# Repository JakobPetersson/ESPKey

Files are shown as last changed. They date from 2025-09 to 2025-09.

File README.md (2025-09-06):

### What the heck is this anyway?
ESPKey is a small device which can be implanted into facility access control systems.  ESPKey is compatible with pretty much every door that requires a card swipe or tap with optional pin code to unlock.  It even works on many systems requiring finger print or other biometric authentication.  Inserting an ESPKey behind a card reader is better than a skimmer because not only can it log all authorized use of a system, it can also inject or replay captured credentials.  Once ESPKey shows you what credentials work on this door, use your favorite RFID tools to clone or simulate those credentials for use on other doors.  Want to show someone how insecure their facility is?  This is an incredibly easy way to start.

In case you need a simple access control system to play with, ESPKey can do that too.  All you need is a card reader, ESPKey and some device to be controlled (like a door lock, electric strike, magnetic lock or just an indicator light).  ESPKey replaces the giant door controller, allowing you to build a simple mobile test lab.  Or a great little portable RFID credential sponge, ready to be hand carried or installed in any heavily trafficked area.

### Releases
Have a look [over here](https://github.com/octosavvi/ESPKey/releases/latest) for the latest pre-built firmware and UI release.

### Build instructions
1. [Install PlatformIO Core](http://docs.platformio.org/page/core.html)
2.  Run these commands:

```shell
# Build project
$ pio run
```

```shell
# Upload firmware
$ pio run --target upload
```

```shell
# Build specific environment
$ pio run -e esp12
```

```shell
# Upload firmware for the specific environment
$ pio run -e esp12 --target upload
```

```shell
# Clean build files
$ pio run --target clean
```

3. Launch html_src/publish.sh to generate ui-update.sh. When connected to ESPKey's web server, launch ui-update.sh to upload the files that make the web UI.

### Usage
Check out [this great documentation](https://redteamtools.com/espkey) put together by Babak of Red Team Tools.

### Hardware
Hardware can be [purchased](https://redteamtools.com/espkey) or have a look in the [hardware](hardware/) directory if you want to build your own.

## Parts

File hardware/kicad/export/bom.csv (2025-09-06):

Designator | Footprint | Quantity | Value | LCSC Part #
C1, C4 | C_0805 | 2 | 22u | C45783
C2, C5 | C_0603 | 2 | 100n | C14663
D1 | LED_0603 | 1 | PWR | C2286
L1 | ELL4_M-small | 1 | 3.6uH | C167827
Q1, Q2, Q3 | SOT-23 | 3 | 2N7002 | C8545
R1, R2 | 0603 | 2 | 75k | C23242
R10, R12, R13, R15, R16, R4, R5, R6, R7, R8, R9 | R_0402 | 11 | 12k7 | C25853
R11, R14, R17 | R_0402 | 3 | 22k | C25768
R18 | R_0402 | 1 | 330 | C25104
R3 | 0603 | 1 | 24k | C23352
U1 | SOT-23-6 | 1 | RT6212A/B | C250402
U2 | ESP-12-SMD | 1 | ESP-12

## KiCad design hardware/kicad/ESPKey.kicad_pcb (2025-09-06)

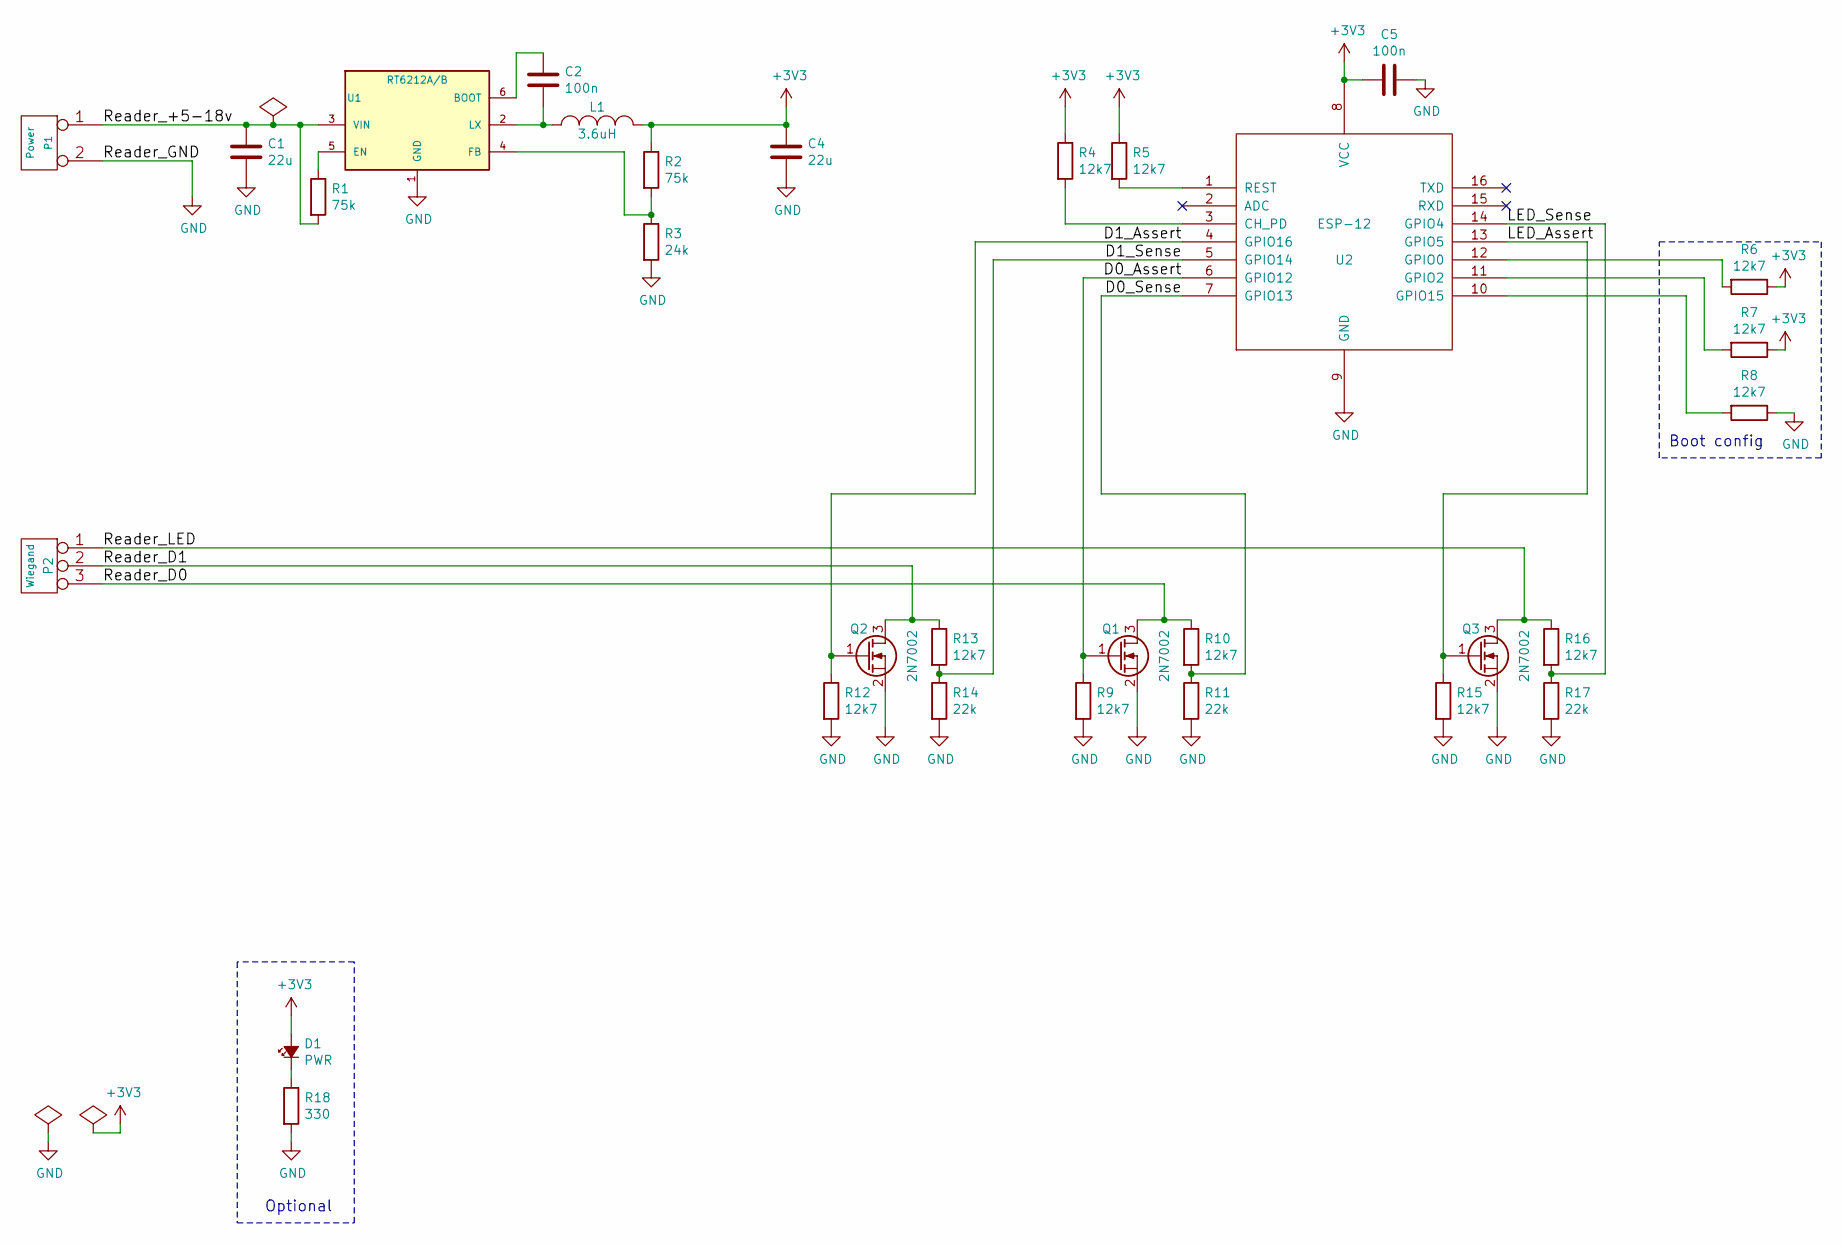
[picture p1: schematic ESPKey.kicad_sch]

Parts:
C1, C4: 22u; C_0805
C2, C5: 100n; C_0603
D1: PWR; LED_0603
L1: 3.6uH; ELL4_M-small
P1: Power; SSL_DW_IDC_02
P2: Wiegand; SSL_DW_IDC_03
Q1, Q2, Q3: 2N7002; SOT-23
R1, R2: 75k; R_0402
R3: 24k; R_0402
R4, R5, R6, R7, R8, R9, R10, R12, R13, R15, R16: 12k7; R_0402
R11, R14, R17: 22k; R_0402
R18: 330; R_0402
U1: RT6212A/B; SOT-23-6
U2: ESP-12; ESP-12-SMD

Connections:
+3V3: C4.2, C5.2, D1.2 (A), L1.2, R2.1, R4.1, R5.1, R6.1, R7.1, U2.8 (VCC)
/D0_Assert: Q1.1 (G), R9.1, U2.6 (GPIO12)
/D0_Sense: R10.2, R11.1, U2.7 (GPIO13)
/D1_Assert: Q2.1 (G), R12.1, U2.4 (GPIO16)
/D1_Sense: R13.2, R14.1, U2.5 (GPIO14)
/LED_Assert: Q3.1 (G), R15.1, U2.13 (GPIO5)
/LED_Sense: R16.2, R17.1, U2.14 (GPIO4)
/Reader_+5-18v: C1.2, P1.1, R1.2, U1.3 (VIN)
/Reader_D0: P2.3, Q1.3 (D), R10.1
/Reader_D1: P2.2 (PM), Q2.3 (D), R13.1
/Reader_LED: P2.1, Q3.3 (D), R16.1
GND: C1.1, C4.1, C5.1, P1.2 (PM), Q1.2 (S), Q2.2 (S), Q3.2 (S), R3.2, R8.1, R9.2, R11.2, R12.2, R14.2, R15.2, R17.2, R18.2, U1.1 (GND), U2.9 (GND)
unnamed: D1.1 (K), R18.1
unnamed: C2.2, U1.6 (BOOT)
unnamed: R1.1, U1.5 (EN)
unnamed: R2.2, R3.1, U1.4 (FB)
unnamed: C2.1, L1.1, U1.2 (LX)
unnamed: R4.2, U2.3 (CH_PD)
unnamed: R6.2, U2.12 (GPIO0)
unnamed: R7.2, U2.11 (GPIO2)
unnamed: R8.2, U2.10 (GPIO15)
unnamed: R5.2, U2.1 (REST)

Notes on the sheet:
Optional
Boot config

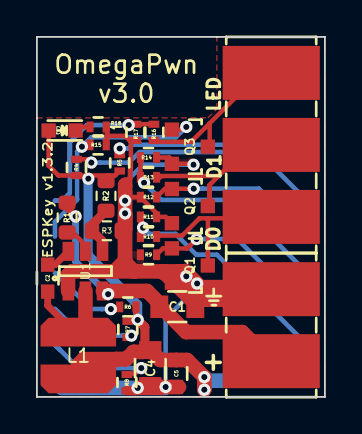
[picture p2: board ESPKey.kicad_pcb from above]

Board: 2 copper layers, 16.0 x 20.0 mm, 31 parts (1 on the bottom side), 22 nets.

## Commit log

2025-09-06 Open KiCad design in current version of KiCad and remap symbols
    [ESPKey.kicad_pcb, ESPKey.kicad_sch]
2025-09-06 Square the pcb
    [ESPKey.kicad_pcb]
2025-09-06 Remove url from front silkscreen
    [ESPKey.kicad_pcb]
2025-09-06 Ignore more directories in KiCad project
2025-09-06 Remove old gerber-files
    [ESPKey-B.Cu.gbr, ESPKey-B.Mask.gbr, ESPKey-B.Paste.gbr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]
2025-09-06 Add KiCad lock-files to gitignore
2025-09-06 Add KiCad fabrication-toolkit-options.json
2025-09-06 Remove silkscreen identifier for P1 and P2
    [ESPKey.kicad_pcb]
2025-09-06 Move silkscreen for "O"-pad
    [ESPKey.kicad_pcb]
2025-09-06 Add LCSC PN filed to all symbols/components
    [ESPKey.kicad_pcb]
2025-09-06 Unlock U2 and add missing LCSC PN property
    [ESPKey.kicad_pcb]
2025-09-06 Exclude P1 and P2 from BOM
    [ESPKey.kicad_pcb]
2025-09-06 Exclude U2 from BOM
    [ESPKey.kicad_pcb]
2025-09-06 Add JLCPSB part numbers to all components
    except P1, P2, U2, C3
    [ESPKey.kicad_pcb]
2025-09-06 Add OmegPwn 3.0 silkscreen
    [ESPKey.kicad_pcb]
2025-09-06 Update L1 JLSC PN
    [ESPKey.kicad_pcb]
2025-09-06 Remove schematic pdf
    [ESPKey.kicad_pcb]
2025-09-06 Remove unused component C3
    [ESPKey.kicad_pcb, ESPKey.kicad_sch]
2025-09-06 Change footprint of R1, R2, R3 to 0603
    [ESPKey.kicad_pcb]
2025-09-06 Add OmegaPwn logo on back silkscreen
    [ESPKey.kicad_pcb]
2025-09-06 Add export of pcb for jlcpcb
    [bom.csv, positions.csv]
2025-09-06 Update silkscreen for wiegand pads
    [ESPKey.kicad_pcb]
2025-09-06 Adjust logo location on back silkscreen
    [ESPKey.kicad_pcb]
